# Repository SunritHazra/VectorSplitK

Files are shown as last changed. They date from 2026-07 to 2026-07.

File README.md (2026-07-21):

# VectorSplitK

An open-source, wireless, high-profile 42-key mechanical split keyboard. Built around the powerful Seeed Studio XIAO nRF52840, the VectorSplitK features an aggressive columnar stagger, custom-modeled flat profile keycaps, and a robust dual-case mechanical assembly. This project is my first split keyboard. The PCB was made entirely in KiCad and the CAD was done in Autodesk Fusion.

> Full day-by-day design log, decisions, and dead ends: [JOURNAL.md](./JOURNAL.md)

**Project stats:** 14 build-log days · ~40h 20m total design time · 100% designing progress, 0% building progress (as of the latest journal entry)

**On the name:** Follows the author's personal naming convention for electronics projects (used previously for *hackpad* and *devboard*) — a descriptive word, a short form of the project's defining trait ("Split"), and a single trailing letter — giving **VectorSplitK**.

---

## Renders

### Standard Top View

Render 1

### Isometric Split Profile

Render 2

### Rear Profile (USB-C & Alignment)

Render 3

---

## Hardware Architecture

### 1. Electrical Schematic

The electrical system uses hierarchical sheets in KiCad to define identical left and right sides. It resolves typical multi-sheet duplicate ground issues by utilizing sheet-specific power flags (${SHEETNAME}_GND).

Main Sheet



Left Half Matrix



Right Half Matrix



### 2. Footprints

- **Switch Footprints:** High-profile `acheron_MXH:MX100H` (1.00u) and `acheron_MXH:MX150H` (1.50u) hotswap-ready switches (42 total, 21 per side).
- **Diodes:** `Diode_SMD:D_SOD-123` (42 total, 1 per key).
- **Mounting Holes:** `MountingHole:MountingHole_3.2mm_M3_DIN965_Pad` (8 total, 4 per side).
- **Resistors:** `Resistor_SMD:R_0805_2012Metric` (4 total, 2 per side).
- **Integrated Circuit:** `modified-XIAO-nRF52840-SMD:modified-XIAO-nRF52840-SMD` (2 total, 1 per side).
- **Testing Points:** `TestPoint:TestPoint_Pad_D2.0mm` (4 total, 2 per side).
- **Mousebites:** Clean PCB snapping using `PCM_marbastlib-various:mousebites_5p5mm_easysnap` (3 break-offs).

### 3. Printed Circuit Board Assembly

Designed for rugged reliability and high-profile ergonomics using the custom footprints above.

KiCad PCB Window



KiCad PCB Render



KiCad PCBA Render



KiCad PCB Back Side



KiCad PCBA Back Side



- **Design files:** [`/PCBA`](./PCBA)

### 4. Enclosure & CAD Assembly

Designed from scratch in Autodesk Fusion, featuring integrated battery slots, precise USB-C ports, and secure brass threaded insert sockets.

file structure of fusion



top case and bottom case together in fusion



section analysis in fusion showing the screw assembly



- **Tolerance Offset:** 0.2 mm case-on-case fit alignment.
- **Plates:** Structural upper case acts as a switch plate, anchoring switches securely.
- **Keycaps:** Custom-modeled 1.00u and 1.50u flat profile MX-stem keycaps tailored for 3D printing.
- **CAD files:** [`/CAD`](./CAD)

---

## Libraries & References

**KiCad libraries used:**
- [mito-keyboard](https://github.com/mito-keyboard/sito-simplified/tree/sain) — base keyboard library
- [marbastlib](https://github.com/ebastler/marbastlib) — mousebite & hardware footprints
- [Panelization](https://github.com/madworm/Panelization.pretty) — panelization footprints
- [Seeed XIAO KiCad Library](https://github.com/Seeed-Studio/OPL_Kicad_Library/blob/master/XIAO%20Family/XIAO.kicad_sch) — XIAO nRF52840 schematic symbol

**Layout & edge-cut inspiration** (referenced for switch arrangement and board outline conventions):
- [mito-keyboard](https://github.com/mito-keyboard/mito-simplified/tree/main)
- [TaoTeChing](https://github.com/sudo-apt-install-tap/TaoTeChing)
- [OVERRIDE-X3D-Split-Keeb](https://github.com/DevX-Dragon/OVERRIDE-X3D-Split-Keeb)

**Keycap reference model:** [Flat MX Keycaps — Printables](https://www.printables.com/model/467351-flat-mx-keycaps), used as a base to project and re-model custom 1.00u/1.50u profiles.

---

## Design Notes

**Columnar stagger layout:** Switches placed on a 20 mm grid; second and fourth rows shifted 10 mm up, the middle row shifted 20 mm up, with board edges drawn 5 mm out from the outermost keys.

**Hierarchical sheet grounding:** KiCad hierarchical sheets duplicate net names by default, which merged the left/right ground nets into one. Fixed using sheet-specific power flags (`${SHEETNAME}_GND`), producing distinct `Left_GND` and `Right_GND` nets per half.

**Case construction (Fusion 360):** Built symmetrically — one side of the PCB modeled, then mirrored — with:
- Screw hubs extruded directly from the PCB's mounting hole positions
- A battery cavity sized to the WLY394058 LiPo and centered relative to the four mounting screws
- A USB-C cutout on the lower case wall, offset slightly oversized for clearance

**Keycap modeling:** 1.00u caps built by lofting projected upper/lower faces of a reference keycap, then hollowing and adding a stem + cross-hub. 1.50u caps were derived by splitting the 1.00u shape, spacing the halves 9 mm apart, and bridging the gap. Stem geometry was verified by cutting the actual switch stem shape directly into the keycap model to guarantee fit.

**Upper case (switch plate):** Modeled by projecting all switch bodies into a sketch, offsetting 1 mm around each switch and 1.5 mm along the walls, then extruding to the wall thickness (4.05 mm) with screw-hole pillars extended up from the PCB. Outer walls were thinned via a −0.8 mm facial offset on the curved edges for a lighter profile. Corner/cutout dimensions (14.70 × 14.70 mm switch openings, 0.705 mm corner radius) were carried over from the author's earlier hackpad build.

**Design refinements:** The SoC position, PCB mounting holes, and upper-case mounting holes were all iterated to (1) clear the USB-C cable path symmetrically on both halves, (2) keep mounting holes equidistant from the three nearest switches for insert clearance, and (3) keep the upper-case screw geometry in sync with the final PCB layout.

---

## Fabrication & Testing

- **Electrical Rule Check (ERC)** run after schematic completion to catch connection errors before layout.
- **Design Rule Check (DRC)** run after routing, with remaining clearance/edge errors resolved before export.
- **Silkscreen:** Front Fab and Back Fab converted to Back Silkscreen; User.Drawings converted to Front Silkscreen and User.Eco1 to Back Silkscreen; testing points manually labeled and text centered relative to switches. Author name, project name, and build month/year added to the front silkscreen for the final revision.
- **Gerber export:** Full fabrication output exported as `VectorSplitK_Gerber.zip`.
- **Fab test:** Gerbers test-uploaded to JLCPCB to validate manufacturability ahead of ordering.
- **STEP export:** PCB exported at multiple levels of detail (full detail for reference, minimal/simplified for clean CAD import) to support Fusion 360 case modeling.

---

## Bill of Materials (BOM)

Full sourcing sheet with vendors and pricing: [`/Bill of Materials`](<./Bill of Materials>)

### Electronics & PCBs

- **2x** PCBs (Left & Right snap-apart panels)
- **2x** Seeed Studio XIAO nRF52840 MCU boards
- **2x** WLY394058 3.7V 1000mAh 1S LiPo Batteries (3.9 mm thickness for slim fit)
- **42x** Mechanical switches (MX compatible)
- **42x** Kailh MX Hotswap Sockets
- **42x** SOD-123 SMD Diodes (`1N4148`)
- **4x** `0805` Metric SMD Resistors (2 per side)

### Hardware & Case Assembly

- **M3** Screws (Specific lengths to clamp top and bottom cases)
- **M3** Brass Knurled Heat-Staking Inserts (Pressed into bottom case pillars)
- **1x Set** Custom-printed 1.00u & 1.50u flat keycaps (STEP files included)

### Sourcing

| Component | Vendor |
|---|---|
| PCB Fabrication | JLCPCB |
| Switches & Kailh Hotswap Sockets | Meckeys |
| Diodes, Resistors, SoC, Battery | Robu.in |
| Screws & Knurled Inserts | OnlyScrews |

---

## Firmware

The board runs wireless **ZMK** firmware on the **XIAO nRF52840**, using a custom shield built on the upstream `seeeduino_xiao_ble` board support.

### Matrix

5 columns × 5 rows per half (21 keys/side, 42 total — a 4×5 grid plus 1 thumb key), with `diode-direction = "col2row"` matching the SOD-123 diode orientation on the PCB.

| Signal | XIAO Pin |
|---|---|
| COL_0 | P0.03 |
| COL_1 | P0.28 |
| COL_2 | P0.29 |
| COL_3 | P0.04 |
| COL_4 | P0.05 |
| ROW_0 | P1.15 |
| ROW_1 | P1.14 |
| ROW_2 | P1.13 |
| ROW_3 | P1.12 |
| ROW_4 | P1.11 |

### Config

Firmware lives in [`/zmk-config`](./zmk-config), structured as its own ZMK user-config repo:
zmk-config/
├── build.yaml
├── config/
│   ├── vectorsplitk.keymap
│   ├── vectorsplitk.conf
│   └── west.yml
├── boards/shields/vectorsplitk/
│   ├── vectorsplitk.dtsi
│   ├── vectorsplitk_left.overlay
│   ├── vectorsplitk_right.overlay
│   ├── vectorsplitk.zmk.yml
│   ├── Kconfig.shield
│   └── Kconfig.defconfig
└── .github/workflows/build.yml

Pushing this folder as its own GitHub repo triggers a GitHub Actions build via `build.yaml`, producing `vectorsplitk_left-seeeduino_xiao_ble-zmk.uf2` and `vectorsplitk_right-seeeduino_xiao_ble-zmk.uf2` under the Actions tab, no local toolchain required.

> **Known caveat:** the matrix transform assumes COL_0 is the innermost column (closest to the thumb key) on both halves. If keys type in mirrored left-right order on first flash, reverse the column order in `vectorsplitk.dtsi` — a firmware-only fix, no rewiring needed.

### Flashing

1. Double-tap Reset on the XIAO nRF52840 to mount it as a USB drive.
2. Drag the matching `.uf2` (left or right) onto the drive.

---

## AI as a Design Collaborator

While the hardware engineering, PCB routing, firmware architecture, and 3D CAD modeling were completed manually, AI (Gemini, ChatGPT, and Claude) was used as a technical assistant throughout the project—not to generate designs, but to help research, troubleshoot, validate decisions, and improve documentation.

- **Brainstorming:** Helped refine the project name (**VectorSplitK**).
- **Research & Validation:** Verified switch footprints, component choices, and battery selection.
- **Debugging:** Assisted in resolving KiCad schematic and hierarchical-sheet issues.
- **Design Review:** Discussed engineering trade-offs, BOM costs, and manufacturing decisions.
- **Firmware & Documentation:** Helped architect the initial ZMK firmware configuration, reviewed the PCB matrix for firmware setup, and improved the project's technical documentation.

> **Project Integrity:** All schematics, PCB layouts, routing, CAD models, and mechanical design were created manually in KiCad and Autodesk Fusion. AI was used only for research, troubleshooting, review, firmware guidance, and documentation.

---

## License

This project is licensed under the MIT License - see the [LICENSE](./LICENSE) file for details.

---

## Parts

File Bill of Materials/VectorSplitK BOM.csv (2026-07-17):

VectorSplitK BOM
Component Category | Item | Cost | Side Note | Link
PCBA | PCB [5] | $16.40 | No assembly
 | Cherry Max Key Set [4 (10 each)] | $14.10 |  | https://meckeys.com/shop/accessories/keyboard-accessories/key-switches/cherry-mx-rgb-switch/
 | Hotswap Socket [4 (10 each)] | $3.18 |  | https://meckeys.com/shop/accessories/keyboard-accessories/key-switches/kailh-hot-swap-socket/
 | WLY394058 3.7V 1000mAh 1S LiPo Battery [2] | $7.88 |  | https://robu.in/product/wly394058-1000mah-3-7v-single-cell-rechargeable-lipo-battery/
 | Seeed Studio XIAO BLE nRF52840 [2] | $23.60 | SoC | https://robu.in/product/seeed-studio-xiao-ble-nrf52840/
 | 1N5819-KEXIN-40V 500mV@1A 1A DO-214AC(SMA) Schottky Diode [42] | $0.66 | Diode | https://robu.in/product/1n5819-kexin-40v-500mv1a-1a-do-214acsma-schottky-diodes-rohs/
 | RC0805FR-0780K6L-Yageo-SMD Resistor, 80.6 k? [67] | $0.10 | Resistor | https://robu.in/product/rc0805fr-0780k6l-yageo-smd-chip-resistor-80-6-kohm-%c2%b1-1-125-mw-0805-2012-metric-thick-film-general-purpose/
 | AC0805FR-072ML-YAGEO-Res Resistor 2M? [14] | $0.11 | Resistor | https://robu.in/product/ac0805fr-072ml-yageo-res-thick-film-0805-2m-ohm-1-0-125w1-8w-%c2%b1100ppm-c-pad-smd-t-r-automotive-aec-q200/
 | Total | $66.03
Case | Case Upper [2] | $- | Printed
 | Case Lower [2] | $- | Printed
 | M3 X 12mm Phillips Pan head SS 304 Screw [10] | $0.21 |  | https://onlyscrews.in/products/phillips-pan-head-m3-x-12mm-pack-of-20?currency=INR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
 | M3 X 6mm 3D Printing Brass Threaded Slant Knurled Inserts [10] | $0.50 |  | https://onlyscrews.in/products/m3-x-6mm-3d-printing-brass-threaded-inserts-dia-3mm-length-6mm?currency=INR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
 | Total | $0.71
Taxes & Shipping | Meckeys Shipping | $1.05 | Standard Shipping
 | OnlyScrews Shipping | $0.72 | Standard Shipping
 | E-POST Shipping | $16.73 | Cheapest Option
 | Total | $18.50
Grand Total |  | $85.24

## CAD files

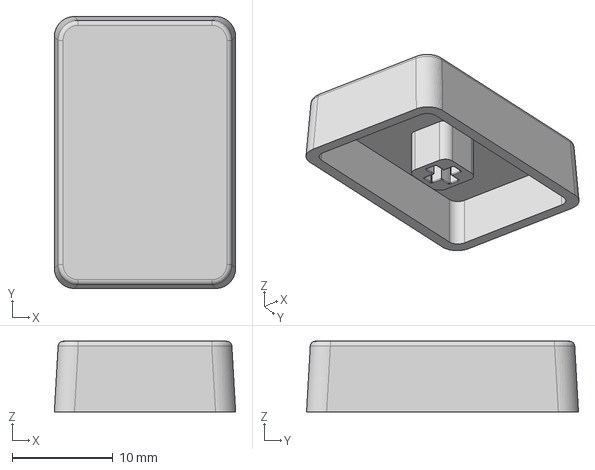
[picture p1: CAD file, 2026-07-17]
CAD/1.50u Keycap.step
18.0 x 27.0 x 7.00 mm

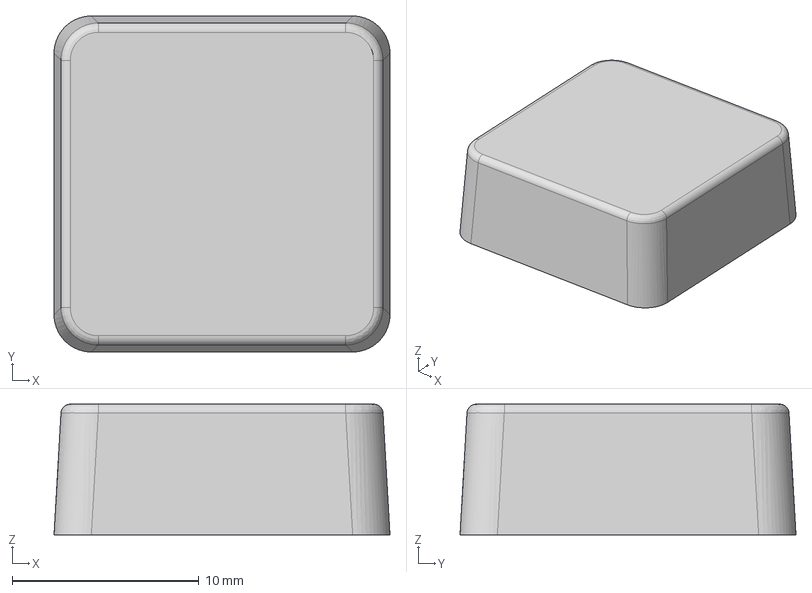
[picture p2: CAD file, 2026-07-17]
CAD/1.00u Keycap.step
18.0 x 18.0 x 7.00 mm

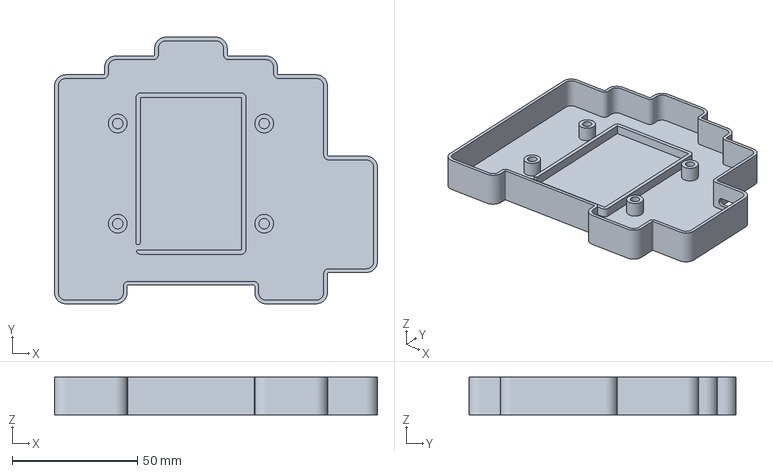
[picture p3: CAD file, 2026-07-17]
CAD/Casing_VectorSplitK v4_Lower Case Left_1_Body1.3mf
129.0 x 106.5 x 15.0 mm

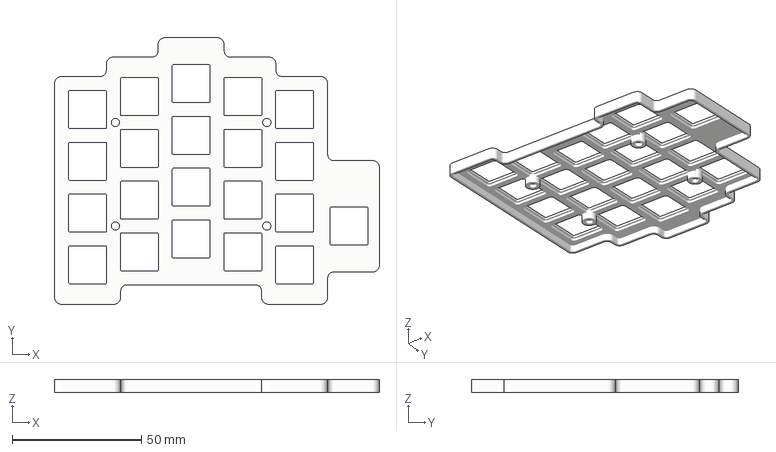
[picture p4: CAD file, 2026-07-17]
CAD/Casing_VectorSplitK v4_Upper Case Left_1_Body1.3mf
125.6 x 103.1 x 5.05 mm

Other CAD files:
CAD/Casing_VectorSplitK v4_Lower Case Right_1_Body1.3mf
CAD/Casing_VectorSplitK v4_Upper Case Right_1_Body1.3mf
CAD/1.00u Keycap.f3d
CAD/1.50u Keycap.f3d

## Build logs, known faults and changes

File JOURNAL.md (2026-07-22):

---
**Title:** VectorSplitK
**Author:** Sunrit Hazra  
**Description:** A wireless high-profile 42 key mechanical split keyboard based on Seeed Studio XIAO nRF52840.  
**Created on:** 30-06-2026  
**Designing Progress (%): 100%**
**Building Progress (%): 0%**
---

# Day 1 — 30.06.2026: Drawing the Schematic & Assigning Footprints

For the split keyboard I have followed the Starter Project Guide from Hack Club Stasis. For the first few minutes, before I started drawing the schmatic, I was asking AI what could I name
my project. And I chose "VectorSplitk" as the name of my project, which follows the same naming format as my previous starter electronics projects like hackpad and devboard.

In this naming system, there are three parts:

* The first phrase is a either a random word or "Hackro".
* The second phrase is a short phrase taken out of the thing's real name like "Dev", "Pad", or "Split".
* The third part is just a letter like "X" or "D"

Thus giving the name "VectorSplitk".

With that done, I opened KiCad and started reading the guide at the same time.

The first step for me was to install the libraries. To be specific, the following libraries:

1. [mito-keyboard](https://github.com/mito-keyboard/sito-simplified/tree/sain)
2. [marbastlib](https://github.com/ebastler/marbastlib)
3. [Panelization](https://github.com/madworm/Panelization.pretty)

Then I started drawing the schematic with the hierierchy determined for left and right sides as stated in the guide. This was my first time working with hierarcheal sheets.

Here's how I did the schematic:

* First I made the matrix using labels, exactly as shown in the tutorial.
* Then I placed the XIAO-nRF52840-SMD symbol by copying it from [here](https://github.com/Seeed-Studio/OPL_Kicad_Library/blob/master/XIAO%20Family/XIAO.kicad_sch).
* Followed by that I made the connections with the XIAO-nRF52840-SMD
* Then it was the break offs (mousebites) which I placed in the main sheet.

Here's how the main Schematic looks:



Here's how the left schematic looks:



Here's how the right schematic looks:



Next were the footprints which were not just simple selections but a whole thought process and understanding. I initially was just trying to copy the footprints without understanding. Turned out that most of the footprints I chose, were replaced by other footprints, and even modified, when I finally understood what I was doing.

Here's how each of them went by: 

1. **Break-offs:** There are 3 of them. I didn't actually chose anything but **panelization:mouse-bite-2mm-slot** came by default since I copied the break-offs from mito-keyboard. But later I switched to **PCM_marbastlib-various:mousebites_5p5mm_easysnap**.
2. **Diodes:** There is a diode for every key, so there are 42 diodes. I had chosen **Diode_SMD:D_SOD-123** since it was suggested in the split keyboard guide.
3. **Mounting Holes:** There are 4 on each side of PCB, so 8 in total. I had selected **MountingHole:MountingHole_3.2mm_M3_DIN965_Pad** for this.
4. **Resistors:** 2 Resistors in each side of PCB. 4 in total. I had selected **Resistor_SMD:R_0805_2012Metric**.
5. **Switches:** 42 of them, 21 on each side of PCB. I initially chose **KEYS: SW_Hotswap Kailh MX** then switched to **Button_Switch_Keyboard:SW_Cherry_MX_1.00u_PCB**.
6. **Testing Points:** 2 on each side of PCB. 4 of them in total. I selected **TestPoint:TestPoint_Pad_D2.0mm** as the footprint.
7. **Integrated Circuit:** 1 XIAO on each side of PCB. 2 in total. I chose **modified-XIAO-nRF52840-SMD:modified-XIAO-nRF52840-SMD** as told in the guide.

Here's the glimpse of the Footprint Assigning Table:



I ran the ERC. Then it was time for the PCB. I didn't know how to design the edges of the board, place the switches in a grid or what to do. So it seemed like I need some inspiration. So, I opened some repositories of people I know who have built a hackpad, to see how to do what I didn't know. I opened these repositories:

1. [mito-keyboard](https://github.com/mito-keyboard/mito-simplified/tree/main)
2. [TaoTeChing](https://github.com/sudo-apt-install-tap/TaoTeChing)
3. [OVERRIDE-X3D-Split-Keeb](https://github.com/DevX-Dragon/OVERRIDE-X3D-Split-Keeb)

I copied the edge cuts from different sources and found a way of awwanging the switches. My idea was to lay the swtiches in a grid (exactly as in the schematic) and then I move the second and second last rows **"X"** mm up and the middle row **"2X"** mm up. Here **"X"** can be 5 mm or 10 mm depending on the spacing.

Here're the lapses of today's session: [VectorSplitK-LPS-1-D1-1](https://lapse.hackclub.com/timelapse/eYyMFjQSes5m) and [VectorSplitK-LPS-1-D1-2](https://lapse.hackclub.com/timelapse/YLruufpElHKS)

**Total time spent: 3h 50m**

---

# Day 2 — 01.07.2026: Placing Components

It was not time for me to execute the idea that I got the day before. I executed it succesfully in two attempts:

* First, I laid out the grid using the positioning tools initially with 15 mm distance between the switches. Then moved the second and fourth row 5 mm up and the third row 10 mm up. I then drew the edges as well.

* But in the first attempt the switches were too close together. Then after correcting the spacing to 20 mm distance between the switches, moved the second and fourth row 10 mm up and the third row 20 mm up. I then drew the edges again at 5 mm distance from the keys.

This is how the pattern looks like:



With the switches placed and the edges drawn, I moved the left side of the PCB to the right and the right to the left.

I was then left with the mousebites, resistors, diodes and the integrated circuits. Here's where and what I placed next:

1. Mousebites between the flat sides of the PCB.
2. XIAO-nRF52840-SMD above the 41st and 42nd key.
3. Each diode above thier respective switches (for SW_41 and SW_42 it was below them)
4. Resistors beside the 41st and 42nd key.

Then I started routing the PCB, but I thought of doing some research using Gemini on the keys I was using and it turned out that I had to change the footprint of my switches as the one I chose were low profile. I wanted high profile mechanical switches.

With that, I changed the footprint for the switches from **Button_Switch_Keyboard:SW_Cherry_MX_1.00u_PCB** to **acheron_MXH.pretty-master:MX100H** for hotswap high profile keys. And I updated the PCB and added models for all the switches and the XIAO-nRF52840-SMD

But then I noticed a connection between the grounds of the two different parts of the PCB. I was confused as I didn't expect this from hierarcheal sheets. I kept it as a problem for the next day.

But, anyways, here's how the PCB looks with the components placed nd edges defined:



Here's the lapse of today's session: [VectorSplitK-LPS-2-D2](https://lapse.hackclub.com/timelapse/7gLMdGcFhW8j)

**Total time spent: 5h 05m**

---

# Day 3 — 02.07.2026: PCB Routing

Today's day was about routing the PCB, but before that I had to solve yesterday;s problem first.

I realised that there are power flags for GND and since the names are same, the only way to change them was to make them sheet specific, which seemed impossible as hierarcheal streets are just duplicates. So whatever change I make also applies to the other one as well. Thanks to Gemini that suggested to use **"${SHEETNAME}_GND"** for the GND power flag. This meant that there will be one **Right_GND** and **Left_GND**. Problem solved!

With the problem solved, I routed all the components of the PCB and and editd the edge cuts so it matches the mousebites footprint template.

Next I edited the Front and Back Silkscreen like this:

1. I converted both the Front Fab (after flipping) and Back Fab to Back Silkcreen.
2. Manually named the testing points.
3. Positioned the text centered to the switches.
4. I converted User.Drawings to Front Silkscreen.
5. I converted User.Eco1 to Back Silkscreen.

Then I ran DRC and fixed the last remaining errors and then also exported the gerbers for a little test. I uploaded it on JLCMC and saw if things were okay.

I had also exported the STEP files. So, I imported them into Fusion for making the case. But looking at the model, it seemed like it would be best if I used 1.50u keys for the 41st and 42nd key. So, I made some adjustments to the position of the two key and rotated them 180 degrees.

I needed 3d model to see how it would look but things didn't go as expected. I saw many people have posted whole collections and sets of keycaps ranging from 1.00u all they way to 7.00u. But there was the same problem with every single one of them: They are not symmetrical and fat, but angled. After a lot of searching and several attempts, I decided to add keycaps later becuase I had a lot other thing to focus on at the moment. Like the case and the battery.

For the battery, I searched in google, took guidance from AI and chose [WLY394058 3.7V 1000mAh 1S LiPo Battery](https://robu.in/product/wly394058-1000mah-3-7v-single-cell-rechargeable-lipo-battery/) from Robu.in for each side of my keyboard. I chose it becuase it is just 3.9 mm thick, so I can easily place it under the PCBA without making the lower case much thick.

For the case, I had to make a sketch. Here's what I did:

1. Imported the PCB into the Fusion workspace.
2. Deleted the shapes except the outermost layer (edge cuts)
3. Deleted the extra faces in the rounded corners.
4. Redrew the sketch with no rounded corners.

I decided to work on this for the next day where I will use offsets and fillets to form the lower case.

But here's the full routed PCB:



Here're the lapse of today's session: [VectorSplitK-LPS-3-D3-1](https://lapse.hackclub.com/timelapse/wJ1pVrpDzbS-), [VectorSplitK-LPS-3-D3-2](https://lapse.hackclub.com/timelapse/x-hgnSQhrMK1) and [VectorSplitK-LPS-3-D3-3](https://lapse.hackclub.com/timelapse/ZtfF6PPONsYK)

**Total time spent: 6h 40m**

---

# Day 4 — 03.07.2026: Trying My Best

I started working with this straight sketch which I firstly mirrored to make it symmetric. I added offset of 2 mm to it which represented the outer edges of the lower case.

The PCB was placed directly above the sketch, so I had to move apart the two sides of the PCB which was really hard since the way the components were arranged required manual selection to first organize them in the browser and them move them. Trying to move the two sides of the PCB apart as bodies just doesen't work.

I had to take a drastically different approach to this. 

Take this imge for example. Every single diode, switch and resistor is a differnet component. This means that either I have to mannually select or take a drastically different approach to this.



It seemed like using simpler STEP file was the way to go since the previous one had tracks, vias and all the little detials. So, I exported the file again with the minimal details. But it still was far from practical. I tried manually selecting the switches, resistors, diodes, one by one to seperate them into different components. Fusion has got to give a way for people to select multiple components from the workspace selection alone, like we do with meshes in Blender.

I have an idea. Let's explore it the next day.

Here's the lapse of today's session: [VectorSplitK-LPS-4-D4](https://lapse.hackclub.com/timelapse/2fYtNShAUCum)

**Total time spent: 1h 10m**

---

# Day 5 — 04.07.2026: Modelling the Lower Case

For the simple version of the model, both sides are supposed to exactly symmetrical and mirrored. Here's how I executed yesterday's idea:

1. Went into KiCad and deleted the right side of the PCB including the mousebites.
2. Redrew the board's left edge in Edge Cuts.
3. Exported it with minimal settings without saving.
4. Imported into Fusion and moved it a little to the left.
5. Mirrored the whole component on the other side.

Simultaneously, I also added fillets and offsets to the sketch and placed them to the left. Then I placed my PCB exactly over it.

Then it was time for the lower casing. Here's what I did:

1. Extended the existing hubs for the screws required to mount the PCB to the lower body of the casing, from the pcb itself.
2. Added a body sized exactly in the dimentions of [WLY394058 3.7V 1000mAh 1S LiPo Battery](https://robu.in/product/wly394058-1000mah-3-7v-single-cell-rechargeable-lipo-battery/) as I chose it before.
3. Positioned the battery in the centre of the PCB based on the rectangle formed due to the four points from the screw position.
4. In KiCad, moved the position of the testing points to the bottom part of the PCB, and routed them.
5. Used the Battery's position as reference to extrude a sketch that will surround the battery pack.

With that, the lower case was completed, and it looks like this:



Here's the lapse of today's session: [VectorSplitK-LPS-5-D5](https://lapse.hackclub.com/timelapse/6bBPs-QqJmJs)

**Total time spent: 2h 05m**

---

# Day 6 — 05.07.2026: Modeling the Keycaps

The very first thing I did was this: I imported the updated STEP file with the correct position of the testing points into Fusion and placed it properly and mirrored it to correct position.

Next were the keycaps. Due to the struggle I was went through to search for the keycaps, it seemed like the best way was to model the keycaps. This meant that I had to 3D print my keys, most likely. Well, that is not a problem since I have a 3D printer thanks to Construct. I thus fimalised the idea of self-modelling the keys.

I needed some source for the model, so I started searching in Printables. For reference I imported the 1u model from [Printables](https://www.printables.com/model/467351-flat-mx-keycaps).

I first modeled the 1.00u keycap and then the 1.50u keycap.

Here's how I did the 1.00u keycap:

* I projected the upper and lower face of the imported keycap.
* Used extrusions to form a flat shape representing the lower face.
* Used loft to join the lower and upper face, forming the shape.
* Used extrusion to cut out the inner part of keycap body.
* Used projected sketch to extrude out the stem and +-like hub.

The 1.00u keycap:



Here's how I did the 1.50u keycap:

* I deleted the keycap stem and +-like hub.
* Split the 1.00u keycap in half.
* Moved both the parts apart by 4.5 mm apart, making the distance 9 mm between them.
* Used extrude to bridge the gap.
* Used the old sketch to form the +-like hub.

The 1.50u keycap:



But I was not totally confident with the internal dimensions of the +-like section. So, I did this:

1. Deleted the like part.
2. Copied the moving part of the switch.
3. Used joint to position it over the stem section.
4. Used combine cut to carve out the geometry.
5. Rotated it and repated the action.

I also made sure that the same geometry exists at the stem section of both the 1.00u and 1.50u keycaps.



With the 1.00u and 1.50u keycaps modeled, it was finally the time to integrate them into the PCBA. Thus, I went into kiCad and then I updated both the **MX100H** and **MX150H** footprints by adding the models.

Then I went into KiCad, deleted one side of the PCB and then exported the STEP file (again) with the simplest possible settings, imported it into fusion, positioned the PCB, mirrored the PCB and finally arranged the components in the browser.



I then made some clearence adjustments in the model and made sure nothing overlaps, and everything fits gracefully.

Then I noticed there was no hole for the USB-C cable to get in. So, I made an extrusion to cut through the lower case wall:



After that I deleted the inner part and then used offset to make the hole a little bigger:



Next thing which I had to model was the upper case, which I will do tommorow.

Here's how the Split keyboard looks:



Here's the lapse of today's session: [VectorSplitK-LPS-6-D6](https://lapse.hackclub.com/timelapse/r0XjsalRWVzc)

**Total time spent: 3h 10m**

---

# Day 7 — 06.07.2026: Modelling the Upper Case

For modelling the upper case, I had a design in mind where the switches will be firmly attached to the upper case and the PCB, so that they act as one single part of the same system. I wanted the screw hoes to extend to the upper face of the upper case.

I needed to figure out a way using which I could know the exact shape needed for properly attaching the switches to the upper case. For this, I visited my hackpad's model to study the dimensions of the uppercase.

I found out that the square was 14.70 mm by 14.70 mm, with rounded corners having length of 0.705 mm. Good thing that I came to know the dimensions but it proved futile.

Here's what I did next:

1. Made a sketch and projected every switch body on the sketch.
   
2. Extruded the sketch and moved it up, as the sketch was on the floor.
   
3. Mirrored the body, arranged both of the bodies in the Browser and added appearence.
   
4. Made a new sketch and made 1 mm offset for switches and 1.5 mm offset for the walls.
   
5. Extruded the switch offsets by 1 mm and the wall offsets by 4.05 mm, to make it thicker.
   
6. Extended the screw hole pads to the uppercase, and then extruded in till the PCB.
   
7. Made the outer wall thinner by using facial offsets on the curved faces by -0.8 mm.
   
8. Combined the parts of the screw hubs and mirrored the combined body.
   

With this, the upper case was completed, leaving almost nothing to model.

Here's how the Split Keyboard looks:





Here's the lapse of today's session: [VectorSplitK-LPS-7-D7](https://lapse.hackclub.com/timelapse/vuXKPHH6yCxN)

**Total time spent: 1h 05m**

---

# Day 8 — 07.07.2026: Journaling

Journaled the day #1 (partly)

Day #1



Here's the lapse of today's session: [VectorSplitK-LPS-8-D8](https://lapse.hackclub.com/timelapse/1Yx_xMfhucab)

**Total time spent: 1h 05m**

---

# Day 9 — 08.07.2026: Journaling

When I was about to continue journaling day #1, I saw I lost all the changes made yesterday as I had forgotten to save my work. So, I played yesterday's sketch and using the screenshots, copied the text and retrived my writing from yesterday.



Here's the lapse of today's session: [VectorSplitK-LPS-9-D9](https://lapse.hackclub.com/timelapse/5DwjW-JZZNnw)

**Total time spent: 0h 30m**

---

# Day 10 — 10.07.2026: Journaling

Journaled the days #1 (full), #2, #3, #4, #5, #6 (partly) and #9.



Here're the lapses of today's session: [VectorSplitK-LPS-10-D10-1](https://lapse.hackclub.com/timelapse/rkP9sRGi9QtF) and [VectorSplitK-LPS-10-D10-2](https://lapse.hackclub.com/timelapse/IaWoMt11Kqi8)

**Total time spent: 4h 35m**

---

# Day 11 — 11.07.2026: Journaling & Modelling

For the first one hour and thirty minutes, I spent time on journaling days #7 and #8 and adding more details to days #1, #4, #5, #6 and #7.

I had actually not completed journaling but I was bored out of my mind, so it felt like it is better to spend time on something else like modelling. So, I needed something to work on. To be specific, a problem to work on.

So, I started to investigate the problems with the system, so that I can work on them and I found these three in my investigation:

1. **SoC Type C Hole:** The current position of the Seeed Studio XIAO nRF52840 was such that it would be very tight for the Type C cable, as it might rub against the lower case. Or even worse, it could not even fit. Thus I had to shift the position of the SoC a little so that it is both symmetrical and also ensures proper fit for the cable. 

2. **PCB Mounting Holes:** The positions of the mounting holes was not very good resulting in the problem of adding knurled inserts. Thus I have to position them exactly in the centre of the nearby switches.

3. **Upper Case Mounting Holes:** The position of the holes on the Upper Case depended on the sketch of projection of the PCB itself. This meant that I had to update the PCB.

I then opened KiCad and one by one solved each problem like this:

* For the first one I first made sure what the position of the Seeed Studio XIAO nRF52840 was on the board relative to its closest corner on the Edge. Then updated that position and copied it to the other side as well with mirrored position. Then imported the PCB after routing.

* For the mounting holes, I also made a similar approach and positioned them at a certain location where the centre of the hole is quidistant from the 3 switches surrounding it. Then imported the PCB after routing.

* For the uppercase, I used the updated PCB to project sketch and use it, after routing the PCB and exporting it. The imported PCB had the correct positions that gave more room for the knurled inserts.

After having the position of the mounting holes fixed, I also centered the battery space by making an offset of 0.13 mm.

Here's how the keyboard looks at last:



Here's the lapse of today's session: [VectorSplitK-LPS-11-D11](https://lapse.hackclub.com/timelapse/CPPEX1s_R7dv)

**Total time spent: 5h 15m**

---

# Day 12 — 13.07.2026: Making the BOM

I started with a minor change I forgot to make the day before, which was adding offsets for the Upper Case so it actually fits with the Lower Case. Previously, there was zero offset, but today I added 0.2 mm offset.

Then I exported my PCB into VectorSplitK_Gerber.zip with all the nescessary files.

With the PCB exported, I simultaneously opened Excel and copied my BOM format from one of my other project and started adding placeholders. I opened JLCPCB and uploaded the ZIP and wasn't quite happy with the numbers. Actually, I don't mind paying $16.40 for the PCB but the shipping is literally $16.73 with E-POST and there are additional customs that Forge ain't gonna pay.

Next I obviously went for the keys, which took a lot of time. I had planned to print my Keycaps, so that was nonw of my concerns. Initially I thought of searching in Amazon or Flipkart, but the deals were pathetic. So, I settled on Cosmic Bite for the keys and later changed to Meckeys, as for the Kalih socket, I was buying from Meckeys.

Next, one by one I went through the Footprint table and chose component for the diodes, resistors, SoC and battery. I chose all of these from Robu.in.

For the screws and the knurled inserts, I had chosen them from OnlyScrews.

Finally, this is the complete BOM:
	


Here's the lapse of today's session: [VectorSplitK-LPS-12-D12](https://lapse.hackclub.com/timelapse/eZuC9CHMVYUR)

**Total time spent: 3h 50m**

---

# Day 13 — 16.07.2026: Journaling & Adding Slikscreen Text

I mostly spent time journaling days #8, #9, #10, #11, #12 and #13 and added pictures to days #1, #2, #3, #4, #5, #7, and the new ones.







I also added text for my name, name of the projet and month and year on which I made it, in the PCB F.Slikscreen like my previous PCBs. Then I re-exported the Fabrication outputs.

Here's what I did to the PCB:



Here're the lapses of today's session: [VectorSplitK-LPS-13-D13-1](https://lapse.hackclub.com/timelapse/p4w9sKsDkTIn) and [VectorSplitK-LPS-13-D13](https://lapse.hackclub.com/timelapse/TeylD5ZsRaPr)

**Total time spent: 2h 20m**

---

# Day 14 — 17.07.2026: Completing the Repository

Today was all about compiling the fruits of the last two weeks of hard work and making the project public-ready. I focused entirely on documentation, visual assets, and setting up the GitHub repository.

Here is exactly what went down today:

* **Visual Assets:** Captured high-quality, clean renders of the completed 3D model from Fusion Teams, Autodesk Fusion, and the PCB layouts from KiCad. These visuals showcase the final assembly, including the custom 1.00u and 1.50u keycaps, the lower case battery compartments, and the physical alignment of the USB-C ports.

* **Documentation (README.md):** Wrote the comprehensive project README.md to serve as the landing page for the repository. I used AI solely as a second set of eyes to polish up my grammar, spelling, and punctuation, ensuring the write-up accurately represents the technical details of the design process.

* **Repository Setup & Licensing:** Cloned my local desktop development files into the remote GitHub repository, organized the folders for Gerbers, CAD files, and logs, and added an open-source license to protect and share the work.

I also added a section in the [README](./README.md) where I wrote how I have used AI in this project, in the section **"AI as a Design Collaborator"**.

With the repository fully structured and the design phase sitting at a proud 100%, the VectorSplitK is officially ready to transition from a digital design to a physical build.

Here's a screenshot of the repository itself:



Here's the lapse of today's session: [VectorSplitK-LPS-14-D14]()

**Total time spent: 3h 20m**

---

# Day 15 — 18.07.2026: The Firmware

Today was the final thing that I had to do before submission: the code.



I added the code to the Firmware.

**Total time spent: 6h 00m**

---

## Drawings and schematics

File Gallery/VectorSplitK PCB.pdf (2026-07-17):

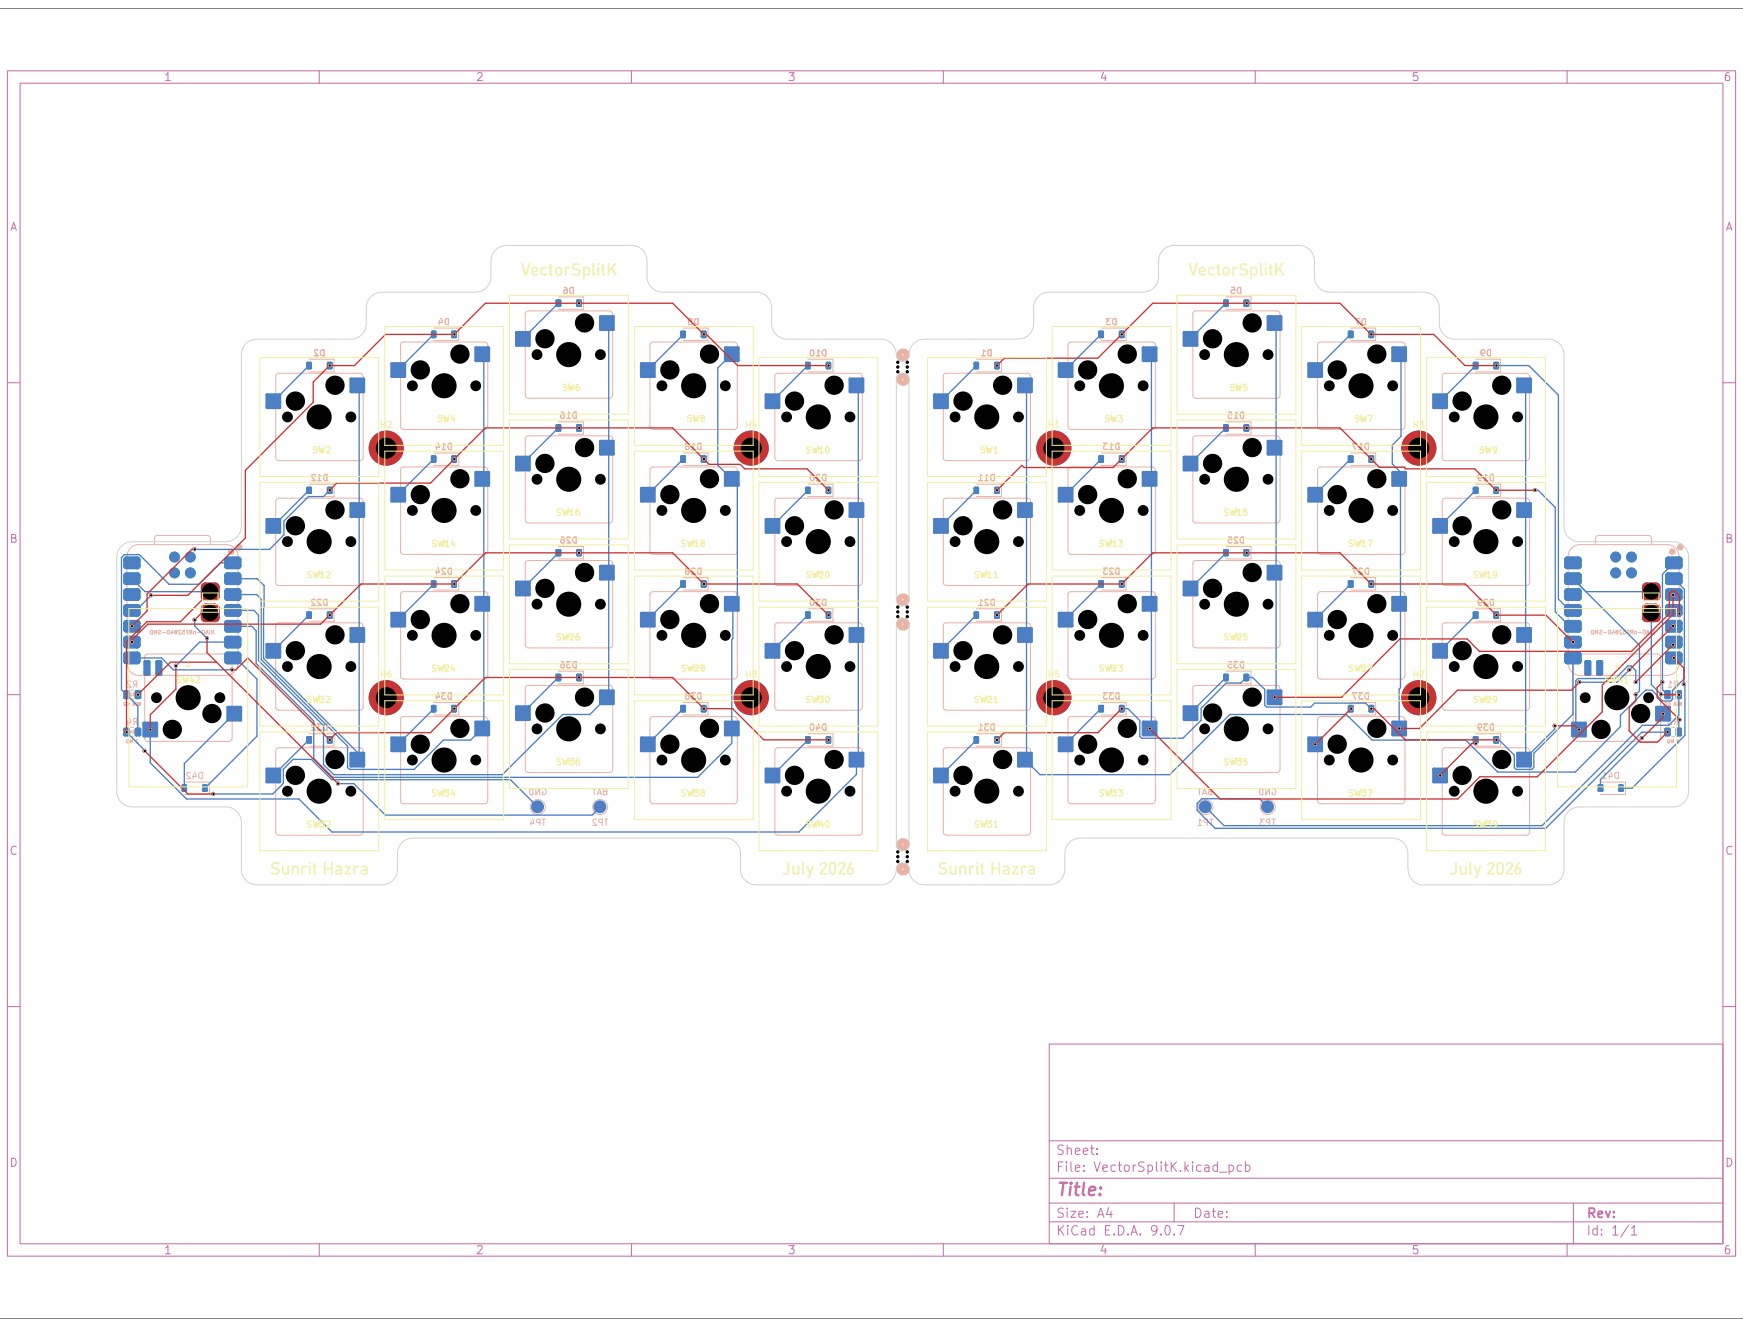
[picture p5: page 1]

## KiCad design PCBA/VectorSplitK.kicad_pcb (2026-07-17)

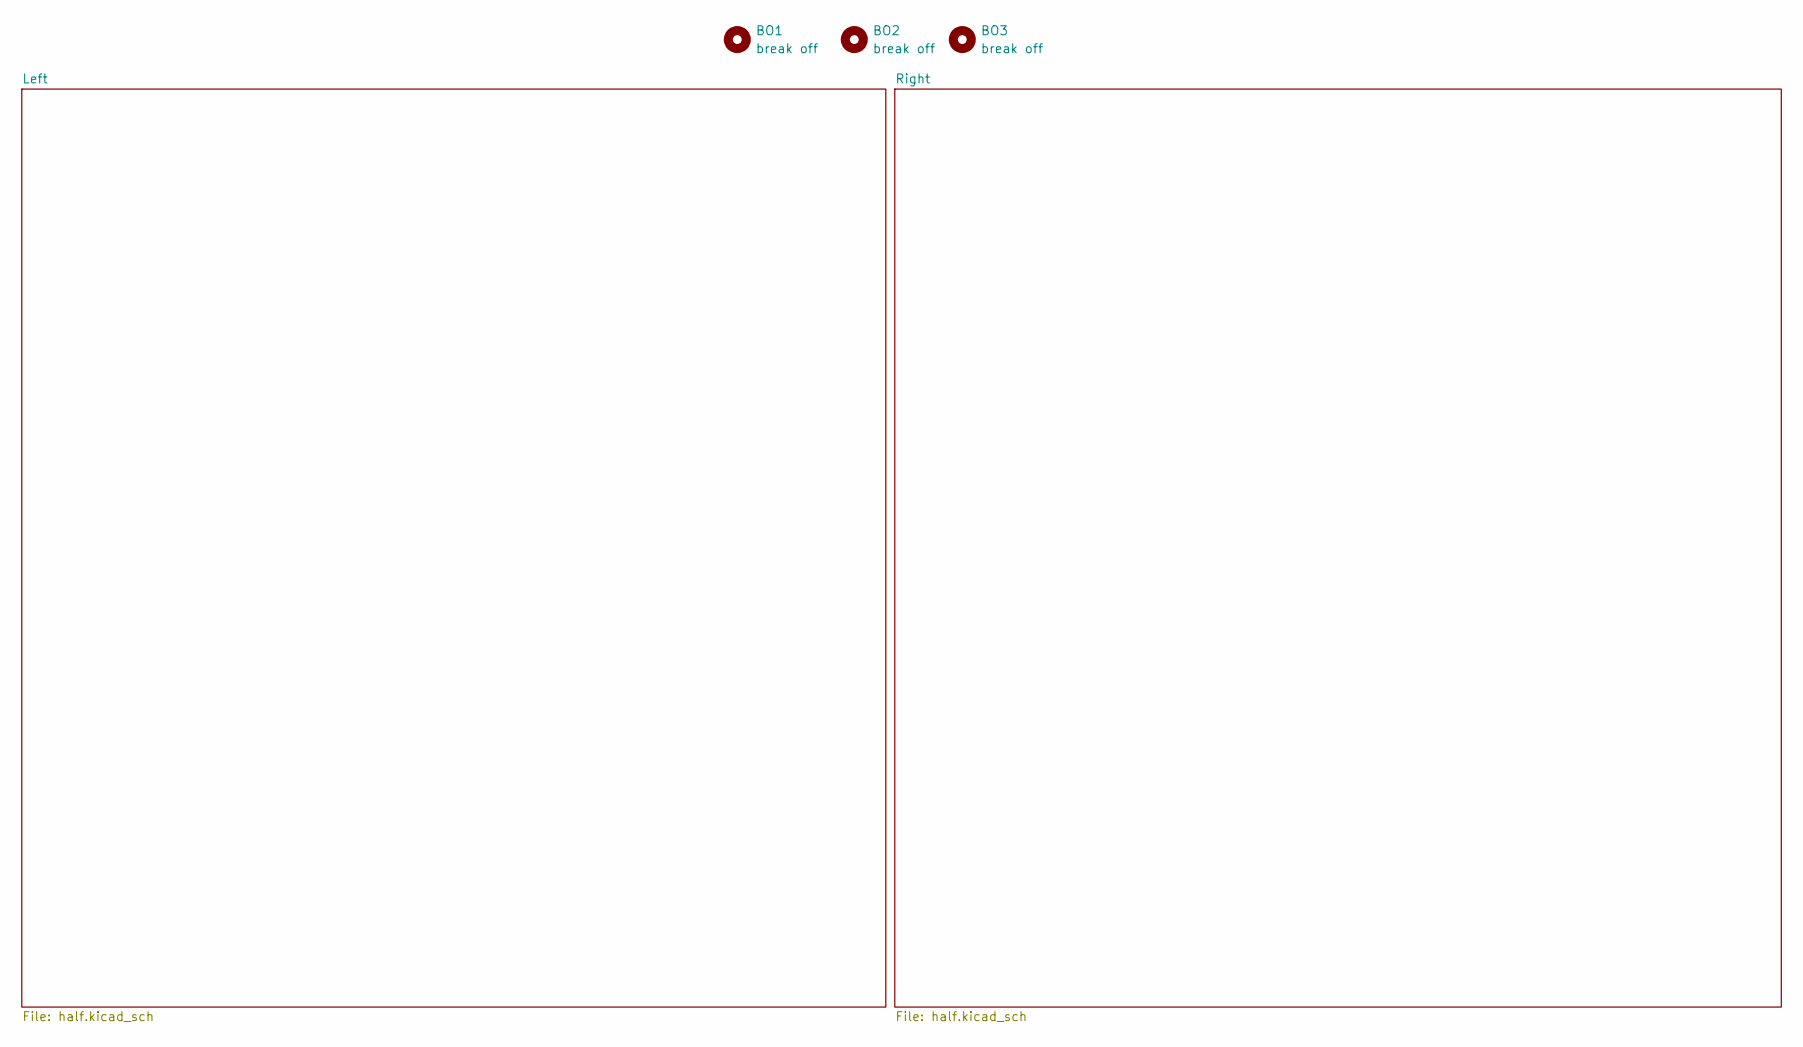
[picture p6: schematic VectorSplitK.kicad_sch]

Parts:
BO1, BO2, BO3: break off; mouse-bite-2mm-slot

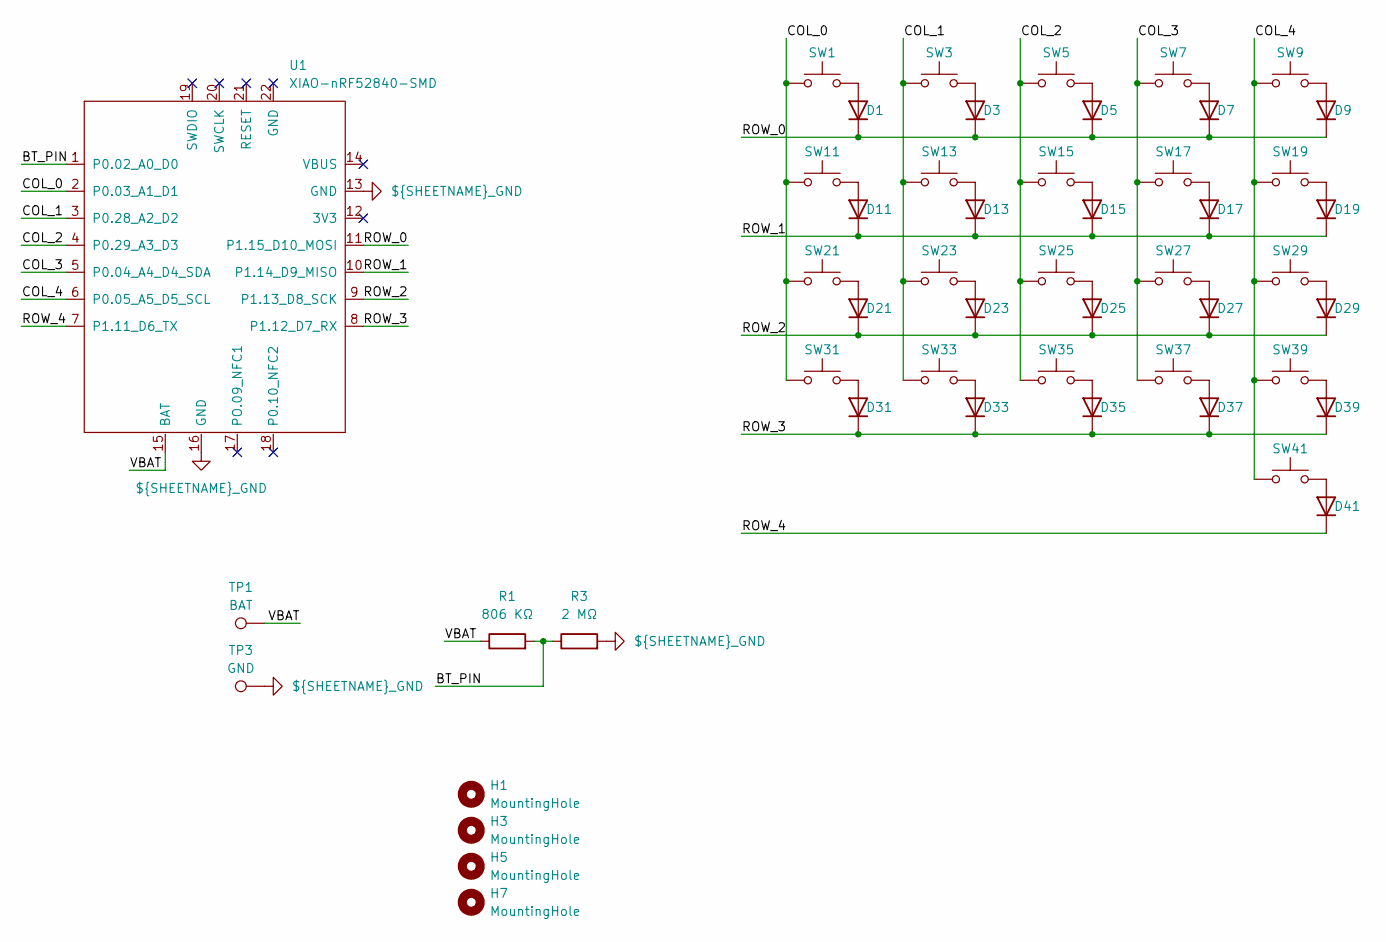
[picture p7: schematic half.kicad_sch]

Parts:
D1, D3, D5, D7, D9, D11, D13, D15, D17, D19, D21, D23, D25, D27, D29, D31, D33, D35, D37, D39, D41: D; D_SOD-123
H1, H3, H5, H7: MountingHole; MountingHole_3.2mm_M3_DIN965_Pad
R1: 806 KΩ; R_0805_2012Metric
R3: 2 MΩ; R_0805_2012Metric
SW1, SW3, SW5, SW7, SW9, SW11, SW13, SW15, SW17, SW19, SW21, SW23, SW25, SW27, SW29, SW31, SW33, SW35, SW37, SW39: SW_Push; MX100H
SW41: SW_Push; MX150H
TP1: BAT; TestPoint_Pad_D2.0mm
TP3: GND; TestPoint_Pad_D2.0mm
U1: XIAO-nRF52840-SMD; modified-XIAO-nRF52840-SMD

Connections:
/Left/BT_PIN: R1.2, R3.1, U1.1 (P0.02_A0_D0)
/Left/COL_0: SW1.1, SW11.1, SW21.1, SW31.1, U1.2 (P0.03_A1_D1)
/Left/COL_1: SW3.1, SW13.1, SW23.1, SW33.1, U1.3 (P0.28_A2_D2)
/Left/COL_2: SW5.1, SW15.1, SW25.1, SW35.1, U1.4 (P0.29_A3_D3)
/Left/COL_3: SW7.1, SW17.1, SW27.1, SW37.1, U1.5 (P0.04_A4_D4_SDA)
/Left/COL_4: SW9.1, SW19.1, SW29.1, SW39.1, SW41.1, U1.6 (P0.05_A5_D5_SCL)
/Left/ROW_0: D1.1 (K), D3.1 (K), D5.1 (K), D7.1 (K), D9.1 (K), U1.11 (P1.15_D10_MOSI)
/Left/ROW_1: D11.1 (K), D13.1 (K), D15.1 (K), D17.1 (K), D19.1 (K), U1.10 (P1.14_D9_MISO)
/Left/ROW_2: D21.1 (K), D23.1 (K), D25.1 (K), D27.1 (K), D29.1 (K), U1.9 (P1.13_D8_SCK)
/Left/ROW_3: D31.1 (K), D33.1 (K), D35.1 (K), D37.1 (K), D39.1 (K), U1.8 (P1.12_D7_RX)
/Left/ROW_4: D41.1 (K), U1.7 (P1.11_D6_TX)
/Left/VBAT: R1.1, TP1.1, U1.15 (BAT)
Left_GND: R3.2, TP3.1, U1.13 (GND), U1.16 (GND)
unnamed: D1.2 (A), SW1.2
unnamed: D3.2 (A), SW3.2
unnamed: D5.2 (A), SW5.2
unnamed: D7.2 (A), SW7.2
unnamed: D9.2 (A), SW9.2
unnamed: D11.2 (A), SW11.2
unnamed: D13.2 (A), SW13.2
unnamed: D15.2 (A), SW15.2
unnamed: D17.2 (A), SW17.2
unnamed: D19.2 (A), SW19.2
unnamed: D21.2 (A), SW21.2
unnamed: D23.2 (A), SW23.2
unnamed: D25.2 (A), SW25.2
unnamed: D27.2 (A), SW27.2
unnamed: D29.2 (A), SW29.2
unnamed: D31.2 (A), SW31.2
unnamed: D33.2 (A), SW33.2
unnamed: D35.2 (A), SW35.2
unnamed: D37.2 (A), SW37.2
unnamed: D39.2 (A), SW39.2
unnamed: D41.2 (A), SW41.2

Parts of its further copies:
D2, D4, D6, D8, D10, D12, D14, D16, D18, D20, D22, D24, D26, D28, D30, D32, D34, D36, D38, D40, D42: D; D_SOD-123
H2, H4, H6, H8: MountingHole; MountingHole_3.2mm_M3_DIN965_Pad
R2: 806 KΩ; R_0805_2012Metric
R4: 2 MΩ; R_0805_2012Metric
SW2, SW4, SW6, SW8, SW10, SW12, SW14, SW16, SW18, SW20, SW22, SW24, SW26, SW28, SW30, SW32, SW34, SW36, SW38, SW40: SW_Push; MX100H
SW42: SW_Push; MX150H
TP2: BAT; TestPoint_Pad_D2.0mm
TP4: GND; TestPoint_Pad_D2.0mm
U2: XIAO-nRF52840-SMD; modified-XIAO-nRF52840-SMD

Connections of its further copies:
/Right/BT_PIN: R2.2, R4.1, U2.1 (P0.02_A0_D0)
/Right/COL_0: SW2.1, SW12.1, SW22.1, SW32.1, U2.2 (P0.03_A1_D1)
/Right/COL_1: SW4.1, SW14.1, SW24.1, SW34.1, U2.3 (P0.28_A2_D2)
/Right/COL_2: SW6.1, SW16.1, SW26.1, SW36.1, U2.4 (P0.29_A3_D3)
/Right/COL_3: SW8.1, SW18.1, SW28.1, SW38.1, U2.5 (P0.04_A4_D4_SDA)
/Right/COL_4: SW10.1, SW20.1, SW30.1, SW40.1, SW42.1, U2.6 (P0.05_A5_D5_SCL)
/Right/ROW_0: D2.1 (K), D4.1 (K), D6.1 (K), D8.1 (K), D10.1 (K), U2.11 (P1.15_D10_MOSI)
/Right/ROW_1: D12.1 (K), D14.1 (K), D16.1 (K), D18.1 (K), D20.1 (K), U2.10 (P1.14_D9_MISO)
/Right/ROW_2: D22.1 (K), D24.1 (K), D26.1 (K), D28.1 (K), D30.1 (K), U2.9 (P1.13_D8_SCK)
/Right/ROW_3: D32.1 (K), D34.1 (K), D36.1 (K), D38.1 (K), D40.1 (K), U2.8 (P1.12_D7_RX)
/Right/ROW_4: D42.1 (K), U2.7 (P1.11_D6_TX)
/Right/VBAT: R2.1, TP2.1, U2.15 (BAT)
unnamed: D2.2 (A), SW2.2
unnamed: D4.2 (A), SW4.2
unnamed: D6.2 (A), SW6.2
unnamed: D8.2 (A), SW8.2
unnamed: D10.2 (A), SW10.2
unnamed: D12.2 (A), SW12.2
unnamed: D14.2 (A), SW14.2
unnamed: D16.2 (A), SW16.2
unnamed: D18.2 (A), SW18.2
unnamed: D20.2 (A), SW20.2
unnamed: D22.2 (A), SW22.2
unnamed: D24.2 (A), SW24.2
unnamed: D26.2 (A), SW26.2
unnamed: D28.2 (A), SW28.2
unnamed: D30.2 (A), SW30.2
unnamed: D32.2 (A), SW32.2
unnamed: D34.2 (A), SW34.2
unnamed: D36.2 (A), SW36.2
unnamed: D38.2 (A), SW38.2
unnamed: D40.2 (A), SW40.2
unnamed: D42.2 (A), SW42.2
Right_GND: R4.2, TP4.1, U2.13 (GND), U2.16 (GND)

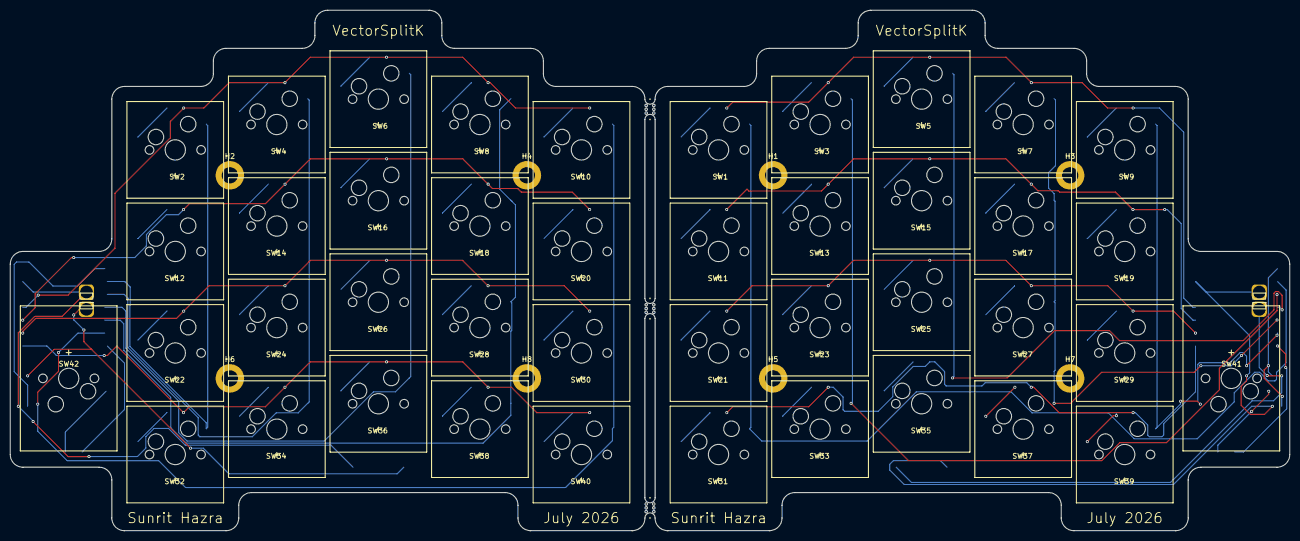
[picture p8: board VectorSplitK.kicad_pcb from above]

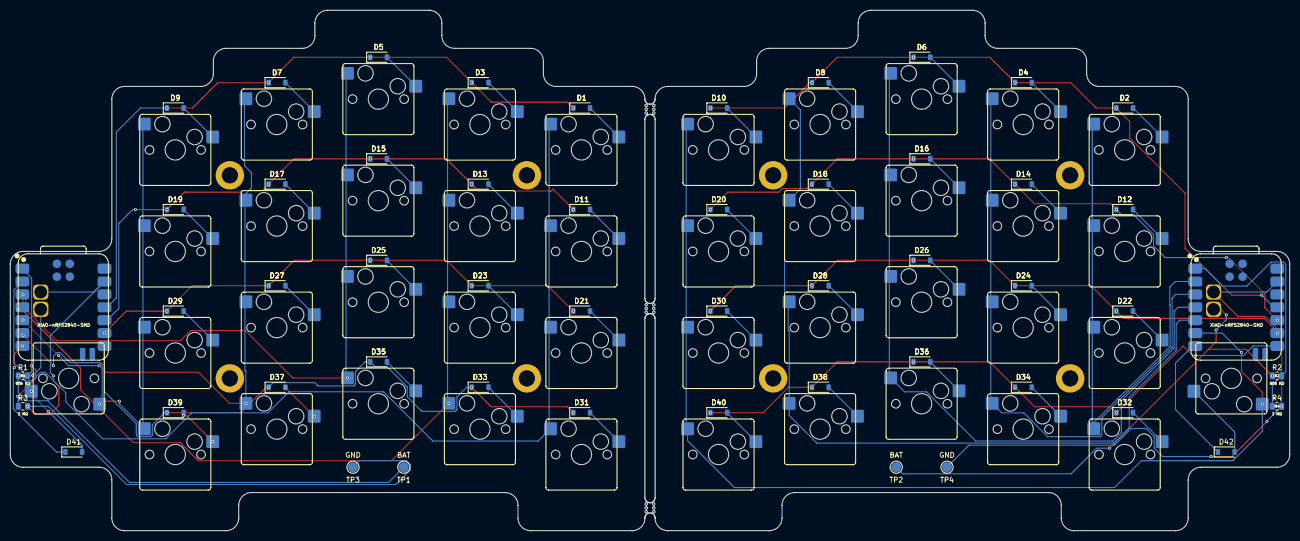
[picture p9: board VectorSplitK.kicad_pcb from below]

Board: 2 copper layers, 252.0 x 102.5 mm, 105 parts (97 on the bottom side), 68 nets.

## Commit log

2026-07-17 updating models
    [1.00u Keycap.f3d, 1.00u Keycap.step, 1.50u Keycap.f3d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]
2026-07-17 Create VectorSplitK PCB.pdf
2026-07-21 Add KiCad PCB images to README
    Added images of KiCad PCB window and render to README.
